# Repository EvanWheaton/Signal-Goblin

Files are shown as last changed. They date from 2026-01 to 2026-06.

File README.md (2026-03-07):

# Signal-Goblin
This is a hack tool that I have come up with.Signal Goblin is a modular, multi-protocol RF exploration and signal analysis platform designed for hackers, hardware tinkerers, and wireless researchers.
Built around compact microcontrollers and stacked RF modules, Signal Goblin is designed to sniff, transmit, emulate, and analyze a wide range of wireless signals — all from a portable, customizable platform.
👾 What Is Signal Goblin?
Signal Goblin is a DIY signal toolkit combining multiple wireless technologies into one expandable device.
It’s designed to:
Capture and analyze sub-GHz RF signals
Read and emulate RFID/NFC tags
Transmit and receive 2.4GHz signals
Send and decode infrared signals
Interface with external storage and peripherals
Serve as a research tool for embedded and wireless experimentation
Think of it as a multi-radio lab bench in your pocket.
🧠 Core Architecture
Signal Goblin integrates:
esp32E n16 – Primary compute module
CC1101 – Sub-GHz RF (300–928 MHz)
PN532 – NFC / RFID (13.56 MHz)
nRF24L01+ – 2.4 GHz communications
IR Transmitter + Receiver – Infrared control and decoding
SD Card Breakout – Data logging and storage
Optional expansion headers for future modules
📡 Supported Protocol Areas
Signal Goblin is designed to experiment with:
Sub-GHz remote protocols
NFC / RFID cards and tags
2.4GHz device communication
Infrared remote control systems
Custom digital signal experimentation

⚠️ This project is intended for educational, defensive, and research purposes only.

🔌 PCB Design
The PCB is a custom multi-layer board designed in KiCad.
Features include:
Dedicated RF routing
SPI bus shared across modules
Modular headers for stackable radios
Proper grounding for signal integrity
Compact footprint for portable builds
Manufacturing-ready Gerber files are included in this repository.
💾 Software Stack

Signal Goblin software includes:
arduino and epstool.py operating system
Python drivers for SPI-based RF modules
Signal logging utilities
CLI-based control interface
Expandable modular architecture
Future goals:
Web-based UI
Signal database system
Automated protocol fingerprinting
Plugin framework
🛠️ Getting Started
Flash Raspberry Pi OS to SD card
Assemble PCB and solder components
Connect modules via SPI

Clone this repository:

Install dependencies
Run initialization script
Bash
Copy code
git clone https://github.com/YOUR_USERNAME/signal-goblin.git
cd signal-goblin
python3 setup.py

🧪 Project Goals
Create a flexible RF experimentation platform
Build a hacker-friendly alternative to commercial multi-tools
Learn deeply about wireless protocols
Maintain full hardware transparency
Enable community contributions and module expansion

🧙 Why “Signal Goblin”?
Because it lurks in the spectrum.
Sniffing.
Listening.
Mischievous, but brilliant.

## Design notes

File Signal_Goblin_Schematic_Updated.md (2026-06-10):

# Signal Goblin TCB - Updated Schematic & Connection Guide (with ESP32-C5 5GHz)
**For EasyEDA Pro**  
**Board:** 105mm × 122mm goblin head body + two 72mm long pointy ears (total width ~249mm ear-to-ear)  
**Now with real 5GHz Wi-Fi 6 via ESP32-C5**  
**Style: Precise. No mistakes. Long ears = antenna superiority.**

## Updated Block Diagram
```
[Left Ear - 72mm long]
     |
Meandered Monopole (~520mm trace, Sub-GHz)
     |
[CC1101] <--- 50Ω feed --- [STM32WB55CCU6]  <-- UART/SPI --> [ESP32-C5-WROOM-1]
     |                                           (coordination + commands)
[PN532 NFC - forehead third eye, coil around edge]
     |
[3.5" ILI9488 TFT + XPT2046 Touch] --- SPI --- [STM32]
     |
[Right Ear - 72mm long]
     |
Meandered 5GHz-optimized antenna (or dual-band capable)
     |
[ESP32-C5 RF port]  <-- Dual-band Wi-Fi 6 (2.4 + 5GHz) + BLE 5 + 802.15.4
     |
[Power: LiPo → TPS63020 Buck-Boost (3.3V clean, high current capable) → Star ground to all noisy parts]
     |
[SD Card | USB-C (BadUSB) | Buzzer | IR TX/RX | iButton | D-Pad + buttons]
```

**Architecture:**
- **STM32WB55**: Main goblin brain. Handles Sub-GHz (CC1101), PN532, IR, iButton, screen + touch, buttons, SD, USB. Low-power RF hacking core.
- **ESP32-C5**: The 5G whore. Handles high-speed dual-band Wi-Fi 6 (finally real 5GHz), additional BLE/Thread. Talks to STM32 over UART for commands (e.g. "connect to WiFi", "send data", "run web server for goblin control").
- Right ear dedicated to ESP32-C5's antenna for maximum 5GHz performance (long ear = massive keep-out + height = excellent radiation pattern, less body detuning when holding).
- Left ear dedicated to CC1101 Sub-GHz.

## Power System (Critical - Don't Fuck This Up)
- Input: LiPo 3.7V nominal → TP4056 charger → TPS63020 buck-boost → clean 3.3V rail (up to 3A capable).
- **Fat traces**: 2mm minimum width for 3.3V main rail on top layer. Layer 2 solid GND pour underneath.
- **Star grounding**: 
  - CC1101 + left ear section has dedicated GND return.
  - ESP32-C5 module has its own fat GND pours and multiple vias to inner GND.
  - PN532, TFT backlight, and STM32 each get clean returns.
- **Decoupling for ESP32-C5** (high current spikes on Wi-Fi TX):
  - Place 22uF + 10uF + multiple 100nF as close as possible to module power pins.
  - Add 4.7uF near RF section.
- VBAT for STM32 backup if wanted.
- No daisy chaining power. Ever.

## Key Pin Connections (Summary)
**STM32WB55CCU6 (UFQFPN48)**
- SPI1 to TFT (CS PA4), Touch (CS PB0), shared SCK/MOSI/MISO.
- SPI2 dedicated to CC1101 (clean RF).
- **UART to ESP32-C5**: USART1 → **PA9 (TX)**, **PA10 (RX)** at 921600 8N1. This is the command link defined in the firmware protocol.
- GPIO for PN532 (I2C or SPI), IR, buttons, buzzer, SD CS, USB.
- Keep RF pins clean.

**ESP32-C5-WROOM-1 Module**
- 3.3V power + massive decoupling.
- UART to STM32.
- Its RF pin → 50Ω trace to right ear antenna feed point.
- GPIOs available for future expansion (status LEDs, extra controls).
- Flash/PSRAM on module (N8R8 recommended).

**Antenna Rules (Long Ears = Your Advantage)**
- **Left Ear (Sub-GHz)**: Meandered monopole, start ~520mm total trace length, 1.0-1.2mm width, snake inside the 72mm triangle ear. 25mm+ keep-out (no GND, no components, no traces under/near). Feed from CC1101 with 50Ω trace. Tune by trimming tip.
- **Right Ear (5GHz primary for ESP32-C5)**: Meandered IFA or monopole optimized for 5GHz (~ quarter-wave ~15mm base, meander to fit and broaden bandwidth). The long 72mm ear gives you insane clearance — this antenna will radiate like a motherfucker compared to cramped boards. Smaller keep-out (~15-20mm) but still use the full ear protrusion. ESP32-C5 supports dual-band so you can tune for good 5GHz performance while having usable 2.4GHz fallback.
- Ground cutouts on inner layers under both ears.
- 4-layer stackup strongly recommended.

## EasyEDA Pro Workflow (Step-by-Step)
1. Create new project → Schematic + PCB.
2. Draw board outline: Goblin head shape (105x122mm) + two long 72mm pointy ears (base ~28mm wide, tapering to point).
3. Place components:
   - 3.5" TFT module at top center (biggest item).
   - PN532 module/coil in forehead center below screen.
   - ESP32-C5-WROOM-1 module in lower jaw/cheek area (space it has room, away from screen edges).
   - STM32WB55 central.
   - CC1101 near left ear base.
4. Route:
   - Power first: Fat 3.3V + star GND.
   - Then SPI buses.
   - UART between MCUs.
   - RF feeds last: 50Ω traces to ear bases, no vias if possible on RF.
5. Antenna zones: Big keep-out polygons on all layers under ears.
6. Run DRC aggressively. Fix everything.
7. Export Gerber (File → Export → PCB Fabrication File).

This is now a dual-MCU beast with real 5GHz capability. The long ears make the antennas actually perform instead of being choked.

Tune the right ear antenna properly or your 5G goblin will be half-assed. Use a VNA.

Next: Update your firmware to handle dual MCU communication. See the firmware file.

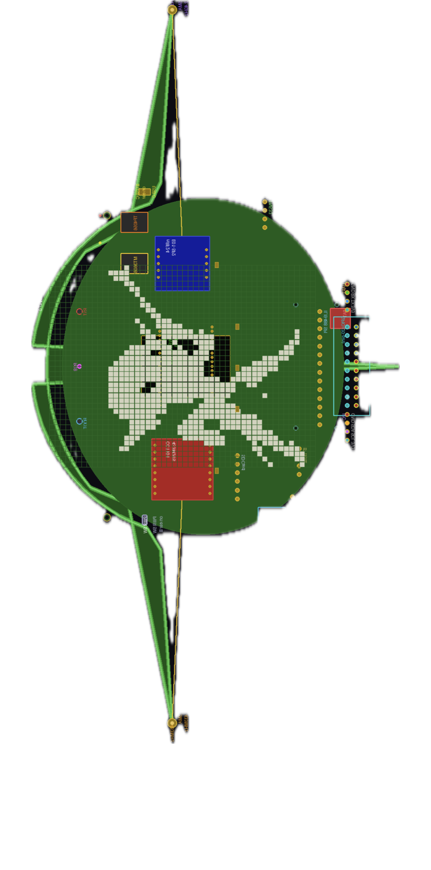
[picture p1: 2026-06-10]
signal_goblin_v7_preview.png

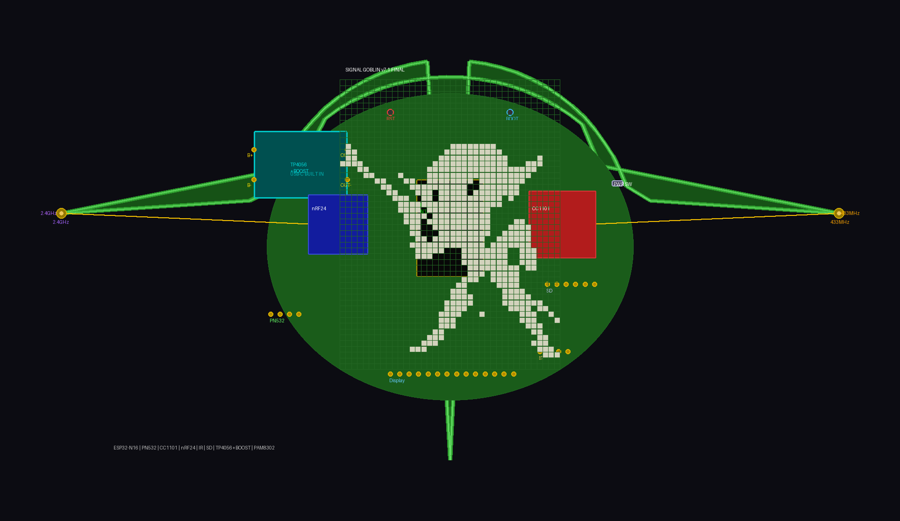
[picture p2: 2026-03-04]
signal_goblin_pcb_preview.png

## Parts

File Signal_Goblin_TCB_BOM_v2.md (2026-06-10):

# Signal Goblin TCB - Bill of Materials (BOM) v2

A comprehensive parts list for building the Signal Goblin multi-tool PCB shaped like a goblin's head with long pointy antenna ears.

---

## Processing & Main Microcontrollers

| Component | Reference | Value | Package | Qty | Manufacturer | Part Number | Description | Notes |
|---|---|---|---|-----|---|---|---|---|
| STM32WB55 | U1 | STM32WB55CCU6 | UFQFPN-48 | 1 | STMicroelectronics | STM32WB55CCU6 | Dual-core wireless MCU (BLE + 802.15.4) | Main processor for Sub-GHz, NFC, UI |
| ESP32-C5 Module | U2 | ESP32-C5-WROOM-1 | SMD Module | 1 | Espressif | ESP32-C5-WROOM-1 | Wi-Fi 6 (802.11ax) + BLE 5 module with 5GHz support | Handles 5GHz Wi-Fi on right ear antenna |

---

## RF & Wireless Modules

| Component | Reference | Value | Package | Qty | Manufacturer | Part Number | Description | Notes |
|---|---|---|---|-----|---|---|---|---|
| CC1101 | U3 | CC1101 | QFN-20 | 1 | Texas Instruments | CC1101RTKR | Low-power Sub-GHz transceiver | Feeds left ear antenna (meandered monopole) |
| PN532 | U4 | PN532 | HVQFN-40 | 1 | NXP | PN5321A3HN/C1 | NFC/RFID controller | Placed in forehead for card reading/writing |

---

## Display & User Interface

| Component | Reference | Value | Package | Qty | Manufacturer | Part Number | Description | Notes |
|---|---|---|---|-----|---|---|---|---|
| 3.5" TFT Display | DISP1 | ILI9488 320x480 SPI + XPT2046 Touch | Custom | 1 | Generic | ILI9488-3.5-SPI-TFT | 3.5 inch SPI TFT touchscreen (resistive) | Top of goblin head, requires good power decoupling |
| 5-Way Joystick / D-Pad | SW1 | 5-Way Switch | SMD | 1 | Generic | 5WAY-JOYSTICK-SMD | Navigation input | Center of board |
| Side Buttons (Left/Right) | SW2-SW3 | Tactile Switch | SMD | 2 | Generic | TACTILE-SW-SMD | Additional buttons | Debounced in firmware |

---

## Storage & Connectivity

| Component | Reference | Value | Package | Qty | Manufacturer | Part Number | Description | Notes |
|---|---|---|---|-----|---|---|---|---|
| MicroSD Card Slot | J1 | MicroSD | SMD | 1 | Generic | MICROSD-8P-SMD | 4-bit SDIO slot | For storage of captures, animations, firmware |
| USB-C Connector | J2 | USB-C | SMD | 1 | Generic | USB-C-16P-SMD | USB Type-C receptacle | For charging + data + potential BadUSB |

---

## Power Management

| Component | Reference | Value | Package | Qty | Manufacturer | Part Number | Description | Notes |
|---|---|---|---|-----|---|---|---|---|
| Power Management IC | U6 | TPS63020 | QFN-14 | 1 | Texas Instruments | TPS63020DSJR | Buck-Boost converter 3.3V 3A | Main power regulator for stable 3.3V under load (screen + WiFi) |
| Battery Charger | U7 | TP4056 or BQ24075 | SOP-8 or QFN | 1 | Generic / TI | TP4056 | LiPo charger with protection | Or upgrade to BQ24075 for better features |
| LDO Regulator (optional) | U8 | TPS73633 | SOT-223 | 1 | Texas Instruments | TPS73633 | 3.3V LDO for sensitive analog/RF | Optional for CC1101/PN532 clean power |
| LiPo Battery Connector | J3 | JST-PH 2-pin | Through-hole | 1 | JST | S2B-PH-K-S | Battery connector | For 3.7V LiPo |

---

## Sensors & I/O

| Component | Reference | Value | Package | Qty | Manufacturer | Part Number | Description | Notes |
|---|---|---|---|-----|---|---|---|---|
| IR LED | D1 | IR LED 940nm | 0805 or TH | 1 | Generic | IR-LED-940nm | Infrared transmitter | For universal remote |
| IR Receiver | U5 | TSOP38238 | Through-hole | 1 | Vishay | TSOP38238 | IR receiver module | For receiving IR signals |
| iButton Port (optional) | J4 | 1-Wire iButton | Through-hole | 1 | Generic | IBUTTON-1WIRE | Dallas/Maxim iButton probe | For legacy access cards |
| Buzzer | BZ1 | Passive Buzzer 5V | SMD or TH | 1 | Generic | BUZZER-5V-SMD | Audio feedback | Mount near bottom |

---

## Passive Components & Support

| Component | Reference | Value | Package | Qty | Manufacturer | Part Number | Description | Notes |
|---|---|---|---|-----|---|---|---|---|
| Decoupling Capacitors | C1-C30 | 100nF + 10µF + 4.7µF | 0402/0603 | ~30 | Generic | CAP-100NF-0402 etc. | Power decoupling + RF | Place close to every IC power pin, especially near ESP32-C5 and CC1101 |
| RF Matching Components (Left Ear) | L1 L2 Cxx | 0402 Inductors/Caps | Various | 6-8 | Johanson or Murata | Specific values from simulation | For CC1101 antenna matching network | Tune with VNA |
| RF Matching Components (Right Ear) | L3 L4 Cyy | 0402 Inductors/Caps | Various | 4-6 | Johanson or Murata | Specific values from simulation | For ESP32-C5 5GHz antenna matching | Critical for performance |
| Resistors | R1-R50 | 0Ω / 10kΩ / 4.7kΩ / 100kΩ | 0402 | ~50 | Generic | RES-10K-0402 etc. | Pull-ups, current limit, configuration | Many for button matrix, LED current, etc. |
| Inductors (power) | L5 L6 | 2.2µH / 4.7µH | 0805 or larger | 3 | Generic | IND-2.2UH-0805 | For buck-boost and filtering | — |
| Crystals | X1 X2 | 32.768kHz + 32MHz | SMD | 2 | Generic | XTAL-32K + XTAL-32M | For STM32 and ESP32 timing | Match ESP32-C5 requirements |

---

## Assembly & Mechanical

| Component | Reference | Value | Package | Qty | Manufacturer | Part Number | Description | Notes |
|---|---|---|---|-----|---|---|---|---|
| PCB | — | 4-Layer FR4 1.6mm | Custom shape | 1 | JLCPCB or PCBWay | Custom | Goblin head + long pointy ears outline | Order with ENIG finish, controlled impedance for RF if possible |
| Antenna Keep-out / Clearance | — | — | — | — | — | — | No components or ground under ears | Critical for antenna performance - leave clear |
| Programming/Debug Header | J5 | SWD + UART | Through-hole or Tag-Connect | 1 | Generic | SWD-10P or Tag-Connect | For STM32 and ESP32 flashing/debugging | — |
| Standoffs / Mounting Hardware | — | M2 or M3 | — | 4-6 | Generic | STANDOFF-M2 | For case mounting if enclosure is added later | — |
| Solder Paste / Flux | — | — | — | As needed | Generic | — | For reflow or hand soldering | Especially for fine-pitch modules |

---

## Off-Board Components

| Component | Reference | Value | Package | Qty | Manufacturer | Part Number | Description | Notes |
|---|---|---|---|-----|---|---|---|---|
| LiPo Battery | — | 1100mAh - 2000mAh 3.7V | Custom | 1 | Generic | LIPO-1100mAh-JST | Lithium polymer battery | With protection circuit, size to fit behind board |
| MicroSD Card | — | 16GB - 32GB Class 10 | — | 1 | SanDisk or Samsung | MICROSD-32GB | Storage media | — |

---

## Notes

- **RF Matching**: Left ear (CC1101) and right ear (ESP32-C5) both require tuning with a VNA for optimal performance.
- **Power Integrity**: Decoupling capacitors are critical—place them as close as possible to IC power pins.
- **Antenna Keep-out**: Absolutely no ground plane or components within 20-25mm of the ear antenna areas.
- **Layer Stackup**: Recommend 4-layer PCB with solid ground plane on Layer 2 and power plane on Layer 3.

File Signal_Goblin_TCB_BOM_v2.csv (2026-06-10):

Component | Reference | Value | Package | Quantity | Manufacturer | Part Number | Description | Status | Design Notes | Sourcing Notes
STM32WB55 | U1 | STM32WB55CCU6 | UFQFPN-48 | 1 | STMicroelectronics | STM32WB55CCU6 | Dual-core wireless MCU (BLE + 802.15.4) | Confirmed | Main processor for Sub-GHz NFC and UI control. Dual-core architecture: M4 primary + M0 for BLE stack | LCSC: Standard stock
ESP32-C5 Module | U2 | ESP32-C5-WROOM-1 | SMD Module | 1 | Espressif | ESP32-C5-WROOM-1 | Wi-Fi 6 (802.11ax) + BLE 5 module with 5GHz support | Confirmed | Handles 5GHz Wi-Fi on right ear antenna. Requires 3.3V at up to 500mA peak | Verify availability - newer chip may have lead time
CC1101 | U3 | CC1101 | QFN-20 | 1 | Texas Instruments | CC1101RTKR | Low-power Sub-GHz transceiver | Confirmed | Feeds left ear antenna (meandered monopole). Recommend adding 10uF bulk cap on power rail | LCSC/Digikey: Good stock
PN532 | U4 | PN532 | HVQFN-40 | 1 | NXP | PN5321A3HN/C1 | NFC/RFID controller | Confirmed | Placed in forehead for card reading/writing. Single-source risk - monitor availability | NXP authorized distributor recommended
3.5" TFT Display | DISP1 | ILI9488 320x480 SPI + XPT2046 Touch | Custom | 1 | Generic | ILI9488-3.5-SPI-TFT | 3.5 inch SPI TFT touchscreen (resistive) | Confirmed | Top of goblin head. Peak current ~200mA. Requires good power decoupling (see C1-C5). Thermal note: mount on FR4 with minimal copper under display | Power dissipation ~600mW typical. Keep SPI traces <50mm
MicroSD Card Slot | J1 | MicroSD | SMD | 1 | Generic | MICROSD-8P-SMD | 4-bit SDIO slot | Confirmed | For storage of captures animations firmware. Use high-speed SD (UHS) compatible slot | LCSC: Standard stock
USB-C Connector | J2 | USB-C | SMD | 1 | Generic | USB-C-16P-SMD | USB Type-C receptacle | Confirmed | For charging + data + potential BadUSB. Add 5.1k pull-down resistors on CC pins for USB 2.0 mode | Common part - multiple suppliers
LiPo Battery Connector | J3 | JST-PH 2-pin | Through-hole | 1 | JST | S2B-PH-K-S | Battery connector | Confirmed | For 3.7V LiPo. Ensure keying matches battery connector | Standard JST stock
Buzzer | BZ1 | Passive Buzzer 5V | 0805 SMD | 1 | Generic | BUZZER-5V-SMD | Audio feedback element | Confirmed | Mount near bottom of head. 85dB @ 4kHz typical. Drive with GPIO + MOSFET if PWM volume control needed | Multiple suppliers
IR LED | D1 | IR LED 940nm | 0805 | 1 | Generic | IR-LED-940nm-0805 | Infrared transmitter | Confirmed | For universal remote control. Forward voltage ~1.5V @ 100mA. Pair with 10-20 ohm current limiting resistor | Digikey/LCSC stock
IR Receiver | U5 | TSOP38238 | DIP-3 through-hole | 1 | Vishay | TSOP38238 | IR receiver module | Confirmed | For receiving IR signals. 38kHz modulation detection. Add 100nF decoupling cap close to power pins | Vishay part - good availability
iButton Port (optional) | J4 | 1-Wire iButton | Through-hole probe | 1 | Generic | IBUTTON-1WIRE | Dallas/Maxim iButton probe | TBD | For legacy access cards. Optional feature - can be omitted in v1 release | Deferred feature
5-Way Joystick / D-Pad | SW1 | 5-Way Switch | SMD | 1 | Generic | 5WAY-JOYSTICK-SMD | Navigation input controller | Confirmed | Center of board. Implement debounce in firmware (20-50ms). Add weak pull-ups on each line | Standard encoder switch
Side Buttons (Left/Right) | SW2-SW3 | Tactile Switch | SMD | 2 | Generic | TACTILE-SW-SMD-6x6 | Additional buttons | Confirmed | Debounced in firmware. 12x12x7.3mm form factor typical. Add weak pull-ups (10k) per button | Bulk sourcing recommended
Power Management IC | U6 | TPS63020 | QFN-14 | 1 | Texas Instruments | TPS63020DSJR | Buck-Boost converter 3.3V 3A | Confirmed | Main power regulator for stable 3.3V under load (screen + WiFi). θJA ~100°C/W - add thermal vias under QFN | TI authorized distributor
Battery Charger | U7 | TP4056 | SOP-8 | 1 | Generic | TP4056 | LiPo charger with protection | Simulated | Upgrade to BQ24075 (QFN) for better features: DPPM voltage regulation higher charge current. Current config: 500mA charge rate | TP4056 cheaper; BQ24075 better performance
LDO Regulator (optional clean rail) | U8 | TPS73633 | SOT-223 | 1 | Texas Instruments | TPS73633 | 3.3V LDO 500mA for sensitive analog/RF | Simulated | Optional for CC1101/PN532 clean power. Recommend including in final design for RF noise isolation. Quiescent current ~15uA | Texas Instruments stock
32.768kHz Crystal | X1 | 32.768kHz | SMD 2012 | 1 | Generic | XTAL-32K-2012 | RTC oscillator for STM32 | Confirmed | For STM32 RTC + sleep modes. 12pF load capacitance typical. Match to STM32 datasheet specs | Standard quartz - good stock
32MHz Crystal | X2 | 32MHz | SMD 2016 | 1 | Generic | XTAL-32M-2016 | Main system clock for ESP32-C5 | Confirmed | ESP32-C5 main oscillator. Verify exact frequency requirement with Espressif datasheet | Check ESP32-C5 requirements
Decoupling Capacitors (main) | C1-C5 | 10uF | 0603 | 5 | Generic | CAP-10UF-0603-16V | Bulk decoupling for power rails | Confirmed | Place close to every major IC power pin (U1 U2 U6). Especially critical near ESP32-C5 and CC1101 PA stage | Ceramic X5R/X7R type
Decoupling Capacitors (bypass) | C6-C35 | 100nF | 0402 | 30 | Generic | CAP-100NF-0402-10V | High-frequency decoupling + RF bypass | Confirmed | Place at VCC pins of all ICs (within 5mm). Also across SPI/I2C pull-up voltage rails. Standard density: 1-2 per IC | Bulk order discount recommended
Decoupling Capacitors (storage) | C36-C38 | 4.7uF | 0603 | 3 | Generic | CAP-4.7UF-0603-10V | Mid-frequency filtering | Confirmed | TPS63020 output filtering and USB power buffering. See TI datasheet for exact placement | X5R ceramic preferred
RF Matching Network (Left Ear - CC1101) | L1-L2 C_match1 | See notes | 0402 | 8 | Johanson / Murata | TBD - pending VNA sim | Impedance matching for CC1101 antenna network | Simulated | PENDING ANTENNA SIM: 50Ω target impedance at 915MHz (North America ISM band). Typical pi-network: 2-15nH series inductors + 0.5-5pF shunt caps. Schedule VNA characterization before PCB release. Target -15dBm match loss | Order after simulation complete
RF Matching Network (Right Ear - ESP32) | L3-L4 C_match2 | See notes | 0402 | 6 | Johanson / Murata | TBD - pending VNA sim | Impedance matching for ESP32-C5 5GHz antenna | Simulated | PENDING ANTENNA SIM: 50Ω target at 5GHz (2.4GHz backup). More complex network than CC1101. Recommend 2-3 stage matching + isolation inductor. Critical for WiFi 6 performance. Tune with VNA | Order after simulation complete
Resistors (pull-ups) | R1-R10 | 10k | 0402 | 10 | Generic | RES-10K-0402-1/16W | SPI/I2C pull-ups button pull-ups | Confirmed | I2C SDA/SCL (2x) SPI chip select (varies) button matrix. Use 10k for 3.3V logic | Standard bulk stock
Resistors (current limit) | R11-R20 | 100-1k | 0402 | 10 | Generic | RES-VALUE-0402-1/16W | LED current limit + bias resistors | Confirmed | IR LED current limit (~20Ω) buzzer drive resistors. Values depend on final layout | Calculate from target currents
Resistors (configuration) | R21-R50 | 0R / 10k / 100k | 0402 | 30 | Generic | RES-VALUE-0402-1/16W | Board-level config/straps | Confirmed | TP4056 charge current programming (2x) PN532 mode select (1x) general purpose pull-ups. | Defer final values to schematic review
Inductors (buck-boost output) | L5 | 2.2uH | 0805 | 1 | Generic | IND-2.2UH-0805-1.5A | TPS63020 output inductor | Confirmed | Required for stable 3.3V buck-boost regulation. ~1.5A max current. Place within 2mm of U6 | Murata LQH31 recommended
Inductors (filtering) | L6 | 4.7uH | 0805 | 1 | Generic | IND-4.7UH-0805-1A | Power rail filtering | Confirmed | Optional additional filtering after TPS63020. Can be omitted if TPS63020 alone meets ripple spec | Standard inductor - good stock
PCB | N/A | 4-Layer FR4 1.6mm | Goblin head shape | 1 | JLCPCB or PCBWay | Custom | Main PCB substrate | Confirmed | Goblin head + long pointy ears outline (Layer 1: Top signal + components Layer 2: Ground plane Layer 3: Power + signal Layer 4: Bottom signal). Specifications: ENIG finish 2oz copper Impedance-controlled traces for RF (ears) min 5mil clearance under antennas. DFM check required | Lead time ~5-7 days post-approval. Budget $150-250 for 5 units.
LiPo Battery | N/A | 1500mAh 3.7V | Custom JST-PH | 1 | Generic | LIPO-1500mAh-3.7V-20C | Main power source | Confirmed | Protected circuit included (TP4056 compat). 20C discharge rating (~30A peak). Runtime: ~4-5 hours typical (WiFi active) | Size constraint: fit behind U2 module. Check final board layout.
MicroSD Card | N/A | 32GB Class 10 U3 | Standard | 1 | SanDisk / Samsung | MICROSD-32GB | Data storage media | Confirmed | For captures animations firmware logs. U3 class guarantees minimum 30MB/s write speed | Purchase once board is finalized
Programming/Debug Header | J5 | SWD + UART | Tag-Connect or Through-hole | 1 | Generic | SWD-10P-TC2030 or custom | STM32 + ESP32 programming interface | Confirmed | Through-hole pads minimum (Tag-Connect optional for final assembly). Includes SWCLK SWDIO UART TX/RX GND + 3.3V | Critical for development - do not omit
Antenna Keep-out / Clearance | N/A | N/A | Ears region | N/A | N/A | N/A | PCB design guideline | Confirmed | No copper components or ground planes under left/right ears. 5mm minimum clearance from PCB edge. Critical for antenna performance - leave clear | Document in PCB layout guidelines
Thermal Management | N/A | Thermal Vias | 0.3mm 0.4mm | As needed | Generic | N/A | Thermal conductor vias | Confirmed | TPS63020 (U6): 8-12 thermal vias 3x3 grid under QFN. ESP32-C5 (U2): 10-15 vias under power pins. ILI9488 (DISP1): Consider via-in-pad | Reduces component junction temps by 20-30°C
Solder Paste / Flux | N/A | SAC305 0.15mm stencil | N/A | As needed | Generic | N/A | Reflow/hand solder consumables | Confirmed | For reflow or hand soldering. Especially for fine-pitch modules (ESP32-C5 PN532). Recommend professional reflow if available | JLCPCB assembly service ~$2-5 per board if outsourced
Standoffs / Mounting Hardware | N/A | M2 or M3 nylon | N/A | 6 | Generic | STANDOFF-M2-NYLON | PCB mounting supports | TBD | For enclosure mounting if case added later. Nylon non-conductive recommended to avoid accidental shorts | Defer to enclosure design phase

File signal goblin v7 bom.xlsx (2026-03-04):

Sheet: Bill of Materials
⚡ SIGNAL GOBLIN v7 — BILL OF MATERIALS
ESP32-WROOM-32E · PN532 · CC1101 · nRF24 · IR · SD · LiPo · PAM8302 · GPIO Expansion
# | Component / Description | Value / Part No. | Qty | Package | Supplier | Est. Unit $ | Ref. Designator | Notes
MICROCONTROLLER
1 | ESP32-WROOM-32E | ESP32-WROOM-32E-N16 | 1 | SMD Stamp Holes 38×18mm | AliExpress / Mouser | $3.50 | U1 | 16MB Flash, 240MHz dual-core, Wi-Fi+BT, 4MB PSRAM
RF MODULES
2 | CC1101 Sub-GHz Transceiver | E07-433M20S (EBYTE) | 1 | SMD Stamp Holes 8×2 pins, 2mm pitch | AliExpress (~$3.73) | $3.73 | U2 | 433MHz, 10dBm, with IPEX pigtail. Connects to right ear SMA
3 | nRF24L01+ 2.4GHz Transceiver | E01-ML01SP2 (EBYTE) | 1 | SMD Stamp Holes 5×2 pins, 2mm pitch | Amazon (~$3.49) | $3.49 | U3 | 2.4GHz, 20dBm PA+LNA. Connects to left ear SMA
4 | PN532 NFC/RFID Reader | Elechouse V3 (Red PCB) | 1 | Breakout Module 4-pin I2C header | Owned | $0.00 | U4 | I2C mode. SDA=GPIO21, SCL=GPIO22
DISPLAY & INPUT
5 | 3.5" TFT LCD Display | ILI9488 SPI + XPT2046 Touch | 1 | 14-pin 2.54mm header | AliExpress | $4.00 | LCD1 | 320×480, 16-bit RGB. SPI bus. Resistive touch
6 | IR Transmitter/Receiver Module | 5V IR Tx+Rx Wireless Module | 1 | 4-pin 2.54mm header | AliExpress / Owned | $1.00 | IR1 | TX=GPIO12, RX=GPIO13
POWER SYSTEM
7 | LiPo Battery | 3.7V 2000mAh Flat Pouch | 1 | JST-PH 2.0 connector | Amazon | $8.00 | BAT1 | 2000mAh, ~6hr runtime. Flat pouch fits behind display
8 | LiPo Charger IC | TP4056 | 1 | SOT-23-6 SMD | LCSC / AliExpress | $0.15 | U5 | Charge via USB-C. CHRG pin → red LED. STDBY → green LED
9 | 5V Boost Converter IC | MT3608 | 1 | SOT-23-6 SMD | LCSC / AliExpress | $0.20 | U6 | Boost 3.7V LiPo → 5V regulated. Enable tied to switch
10 | Boost Inductor | 4.7µH SMD Inductor | 1 | 0805 | LCSC | $0.10 | L1 | For MT3608 boost converter
11 | Output Filter Cap | 10µF 10V Ceramic | 2 | 0805 | LCSC | $0.05 | C1–C2 | MT3608 input + output filter
12 | Decoupling Caps | 100nF Ceramic | 8 | 0402 | LCSC | $0.02 | C3–C10 | One per module: ESP32×3, CC1101, nRF24, TP4056, MT3608, PAM8302
13 | Reverse Polarity Diode | SS14 Schottky | 1 | SOD-123 | LCSC | $0.05 | D1 | Battery polarity protection. Forward voltage 0.3V
14 | Resettable Fuse (PTC) | 500mA Hold, 1A Trip | 1 | 1206 SMD | LCSC | $0.15 | F1 | Overcurrent protection on battery rail
15 | Battery Voltage Divider | 100kΩ + 100kΩ Resistor | 2 | 0402 | LCSC | $0.02 | R1–R2 | Divider mid-point → GPIO36 (ADC). Reads battery %
16 | LED Current Resistors | 330Ω Resistor | 3 | 0402 | LCSC | $0.02 | R3–R5 | Current limit for charge LEDs (red/green) and power LED
17 | USB-C Connector | USB Type-C Through-Hole | 1 | 6-pin TH, 2.54mm | LCSC / AliExpress | $0.30 | J1 | On LEFT EAR BASE. Charging + programming. D+/D- to ESP32
18 | Power Slide Switch | 3-Pin SPDT Slide Switch | 1 | 3-pin TH, 2.54mm | AliExpress | $0.25 | SW3 | On RIGHT EAR BASE. Hard on/off between battery and boost
INDICATORS
19 | RGB LED | WS2812B or 5mm through-hole | 1 | 4-pin TH | AliExpress | $0.20 | LED1 | Signal feedback. Forehead top. GPIO→PWM controlled
20 | Charge LED Red | 3mm or 0402 Red LED | 1 | 0402 | LCSC | $0.05 | LED2 | TP4056 CHRG pin (active low = charging)
21 | Charge LED Green | 3mm or 0402 Green LED | 1 | 0402 | LCSC | $0.05 | LED3 | TP4056 STDBY pin (active low = full)
22 | Power LED Yellow | 3mm or 0402 Yellow LED | 1 | 0402 | LCSC | $0.05 | LED4 | 5V rail indicator
AUDIO
23 | Mono Audio Amplifier IC | PAM8302A | 1 | SO-8 SMD | LCSC / AliExpress | $0.40 | U7 | 2.5W mono amp. SD pin to GPIO for mute control
24 | Speaker | 8Ω 0.5W Mini Speaker | 1 | JST-PH 2-pin | AliExpress | $1.50 | SPK1 | For scan alerts, UI sounds, boot jingle
25 | Audio Filter Cap | 10µF Electrolytic | 1 | Through-hole | LCSC | $0.05 | C11 | PAM8302 input coupling capacitor
CONTROLS
26 | Reset Button | 6×6mm SMD Tactile | 1 | 4-pad SMD | LCSC / AliExpress | $0.05 | SW1 | RESET — forehead left. Pulls EN low. Essential for programming
27 | Boot Button | 6×6mm SMD Tactile | 1 | 4-pad SMD | LCSC / AliExpress | $0.05 | SW2 | BOOT — forehead right. Pulls GPIO0 low for flash mode
STORAGE & EXPANSION
28 | MicroSD Breakout Board | MicroSD Breakout (user-owned) | 1 | 6-pin 2.54mm header | Owned | $0.00 | SD1 | SPI. MISO=GPIO19, MOSI=GPIO23, SCK=GPIO18, CS=GPIO15
29 | GPIO Expansion Header | 2×10 Male Pin Header 2.54mm | 1 | 2×10 TH | AliExpress | $0.20 | J2 | 20-pin: IO0,IO1,IO3,IO16,IO17,IO22,IO34,IO35,IO39,IO26 + PWR
30 | UART Header | 1×4 Male Pin Header 2.54mm | 1 | 1×4 TH | AliExpress | $0.05 | J3 | GND | RX(IO3) | TX(IO1) | 3V3 — debug + serial modules
31 | I2C Header | 1×4 Male Pin Header 2.54mm | 1 | 1×4 TH | AliExpress | $0.05 | J4 | GND | SDA(IO21) | SCL(IO22) | 3V3 — daisy-chain sensors
32 | Power Rail Header | 1×6 Male Pin Header 2.54mm | 1 | 1×6 TH | AliExpress | $0.05 | J5 | GND×2 | 3V3×2 | 5V×2 — power tap for add-ons
RF ANTENNAS & CONNECTORS
33 | SMA Edge Connector (×2) | SMA Female PCB Edge Mount | 2 | 4-pin edge mount | Amazon (25-pack $10.99) | $0.44 | J6–J7 | Right ear = 433MHz (CC1101), Left ear = 2.4GHz (nRF24)
34 | IPEX Pigtail Cable CC1101 | TX433-JKS-IPX20 200mm | 1 | IPEX to SMA Male | Included with E07-433M20S | $0.00 | W1 | Routes CC1101 IPEX pad → right ear SMA connector
35 | IPEX Pigtail Cable nRF24 | IPEX to SMA Pigtail 200mm | 1 | IPEX to SMA Male | Included with E01-ML01SP2 | $0.00 | W2 | Routes nRF24 IPEX pad → left ear SMA connector
36 | SMA Rubber Duck Antenna | 433MHz Whip Antenna | 1 | SMA Male | Included / AliExpress | $1.00 | ANT1 | For CC1101 right ear SMA
37 | SMA Rubber Duck Antenna | 2.4GHz Whip Antenna | 1 | SMA Male | Included with E01-ML01SP2 | $0.00 | ANT2 | For nRF24 left ear SMA
PCB & ASSEMBLY
38 | Signal Goblin PCB v7 | Custom Goblin-Head Silhouette | 5 | 208×107mm 2-layer FR4 1.6mm | JLCPCB / PCBWay | $1.00 | PCB | Black soldermask, HASL finish. Order qty 5 (~$5 total)
39 | SMD Solder Stencil | Top-side Stainless Steel | 1 | Match PCB top layer | JLCPCB / PCBWay | $10.00 | — | Essential for stamp-hole module pads. Top side only
40 | M2.7×5mm Standoff Screws | M2.7 Hex Standoff + Nut | 4 | M2.7 | Amazon / Hardware | $0.20 | — | Board mounting holes at 4 corners
41 | M2×4mm Display Screws | M2 Flat Head + Nut | 4 | M2 | Amazon / Hardware | $0.10 | — | ILI9488 display mounting holes
ESTIMATED TOTAL (excl. owned items) |  |  |  |  |  | ~$55–65 | Includes PCB, stencil, all components

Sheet: ESP32 Pin Map
⚡ SIGNAL GOBLIN v7 — ESP32 GPIO PIN ASSIGNMENTS
ESP32-WROOM-32E-N16 | All unused GPIO available on 20-pin expansion header
GPIO Pin | Connected To | Direction | Interface | Notes
SPI BUS — ILI9488 Display + SD Card
GPIO 18 | SPI SCK | Output | SPI | Shared clock: Display + SD card
GPIO 19 | SPI MISO | Input | SPI | Shared MISO: Display + SD card
GPIO 23 | SPI MOSI | Output | SPI | Shared MOSI: Display + SD card
GPIO 5 | Display CS | Output | SPI/CS | ILI9488 Chip Select
GPIO 2 | Display DC/RS | Output | GPIO | ILI9488 Data/Command select
GPIO 4 | Display RST | Output | GPIO | ILI9488 Hardware reset
GPIO 32 | Display BL | Output | PWM | ILI9488 Backlight (LEDC PWM)
GPIO 15 | SD Card CS | Output | SPI/CS | MicroSD breakout chip select
GPIO 36 | Touch IRQ | Input | GPIO | XPT2046 touch interrupt (input only)
GPIO 33 | Touch CS | Output | SPI/CS | XPT2046 touch controller CS
I2C BUS — PN532 NFC
GPIO 21 | I2C SDA | Bi-dir | I2C | PN532 SDA. Add 4.7kΩ pull-up to 3V3
GPIO 22 | I2C SCL | Output | I2C | PN532 SCL. Add 4.7kΩ pull-up to 3V3. Also I2C expansion header
CC1101 Sub-GHz (SPI)
GPIO 14 | CC1101 CS | Output | SPI/CS | CC1101 Chip Select (separate from VSPI)
GPIO 26 | CC1101 GDO0 | Input | GPIO | CC1101 interrupt / packet ready
GPIO 27 | CC1101 GDO2 | Input | GPIO | CC1101 secondary interrupt
nRF24L01+ 2.4GHz (SPI)
GPIO 25 | nRF24 CE | Output | GPIO | nRF24 Chip Enable (TX/RX control)
GPIO 16 | nRF24 CSN | Output | SPI/CS | nRF24 Chip Select Not
GPIO 17 | nRF24 IRQ | Input | GPIO | nRF24 interrupt (active low)
IR Transmitter / Receiver
GPIO 12 | IR TX | Output | GPIO/PWM | IR transmitter — IRremote library
GPIO 13 | IR RX | Input | GPIO | IR receiver — IRremote library
AUDIO — PAM8302
GPIO 9 | I2S / DAC | Output | DAC | Audio output to PAM8302 input. Use GPIO25/26 DAC or I2S
GPIO 11 | PAM8302 SD | Output | GPIO | PAM8302 shutdown (HIGH=on, LOW=mute)
POWER & SYSTEM
GPIO 36 | Battery ADC | Input | ADC | Voltage divider mid-point. Read battery %. Input-only
GPIO 34 | LDR / Spare | Input | ADC | Photosensitive / spare ADC. Input-only
GPIO 0 | BOOT Button | Input | GPIO | Pull LOW to enter flash mode. Also expansion header
EN | RESET Button | Input | System | Pull LOW via RST button to reset ESP32
GPIO 35 | Spare ADC | Input | ADC | Available on GPIO expansion header. Input-only
RGB LED
GPIO 6 | RGB Data | Output | GPIO | WS2812B data pin. NeoPixel / FastLED library
EXPANSION HEADER (20-pin J2)
GPIO 0 | EXP Pin 1 | In/Out | GPIO | Boot button + expansion. Use carefully
GPIO 1 | EXP Pin 2 / TX0 | Output | UART0 | UART TX debug. Also UART header J3
GPIO 3 | EXP Pin 3 / RX0 | Input | UART0 | UART RX debug. Also UART header J3
GPIO 16 | EXP Pin 4 | In/Out | GPIO | nRF24 CSN — shared with expansion
GPIO 17 | EXP Pin 5 | In/Out | GPIO | nRF24 IRQ — shared with expansion
GPIO 22 | EXP Pin 6 | Output | I2C | I2C SCL — shared with expansion + I2C header
GPIO 34 | EXP Pin 7 | Input | ADC | Input only — ADC capable
GPIO 35 | EXP Pin 8 | Input | ADC | Input only — ADC capable
GPIO 39 | EXP Pin 9 | Input | ADC | Input only (VP) — ADC capable
GPIO 26 | EXP Pin 10 | In/Out | GPIO | CC1101 GDO0 — shared with expansion

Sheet: Ordering Guide
⚡ SIGNAL GOBLIN v7 — ORDERING GUIDE
Source | Item | Search / Part# | Price | Status | Notes
JLCPCB / PCBWay | PCB v7 (qty 5) | signal_goblin_v7_gerbers.zip | ~$5 | ⬜ ORDER | Black soldermask, 2-layer, 1.6mm FR4
JLCPCB / PCBWay | SMD Stencil (top) | Add at PCB checkout | ~$12 | ⬜ ORDER | Top side stainless steel — required for stamp holes
AliExpress | ESP32-WROOM-32E-N16 | ESP32-WROOM-32E N16 | ~$3.50 | ⬜ ORDER | 16MB flash variant
AliExpress | CC1101 E07-433M20S ×4 | E07-433M20S EBYTE with pigtail | $14.92 | ✅ ORDERED | 4-pack with IPEX pigtails
Amazon | nRF24 E01-ML01SP2 | EBYTE E01-ML01SP2 | $3.49 | ✅ ORDERED | Includes SMA antenna + pigtail
Amazon | SMA Edge Connectors ×25 | SMA Female PCB Edge Mount | $10.99 | ✅ ORDERED | 4-pin mechanical, fits ear tips
AliExpress | ILI9488 3.5" TFT | 3.5 inch ILI9488 SPI touch | ~$4.00 | ⬜ ORDER | 320×480, XPT2046 touch
Owned | PN532 NFC Module | Elechouse V3 red PCB | $0.00 | ✅ OWNED | Set to I2C mode via DIP switches
Owned | nRF24L01+ (backup) | Small module | $0.00 | ✅ OWNED | Backup / testing
Owned | SD Card Breakout | MicroSD breakout module | $0.00 | ✅ OWNED | 6-pin SPI
Amazon | LiPo 3.7V 2000mAh | 2000mAh JST-PH 2.0 flat pouch | ~$8.00 | ⬜ ORDER | Flat pouch, JST-PH 2.0 connector
LCSC | TP4056 (×5) | TP4056 | ~$0.75 | ⬜ ORDER | SOT-23-6 LiPo charger IC
LCSC | MT3608 (×5) | MT3608 | ~$1.00 | ⬜ ORDER | SOT-23-6 5V boost converter
LCSC | PAM8302A (×2) | PAM8302A | ~$0.80 | ⬜ ORDER | SO-8 mono audio amp
LCSC | Passives kit | 0402/0805 caps, resistors | ~$3.00 | ⬜ ORDER | 100nF, 10µF, 330Ω, 100kΩ, 4.7µH
LCSC | Misc components | SS14, PTC fuse, LEDs, buttons | ~$2.00 | ⬜ ORDER | Diode, fuse, RGB LED, tactile buttons, slide switch
AliExpress | 8Ω 0.5W Speaker | Mini speaker 8 ohm JST | ~$1.50 | ⬜ ORDER | For audio alerts
AliExpress | IR Tx/Rx Module | 5V IR wireless module | ~$1.00 | ⬜ ORDER | Transmitter + receiver combo
AliExpress | Pin headers assorted | 2.54mm male/female headers | ~$2.00 | ⬜ ORDER | For all module connectors
AliExpress | JST-PH 2.0 connectors | JST PH 2.0 2-pin | ~$1.00 | ⬜ ORDER | Battery + speaker connectors
AliExpress | USB-C connectors ×5 | USB Type-C female through-hole | ~$1.50 | ⬜ ORDER | For left ear base

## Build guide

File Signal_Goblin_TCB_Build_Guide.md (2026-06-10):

# SIGNAL GOBLIN TCB - COMPLETE BUILD GUIDE FOR EASYEDA PRO
## You wanted it finished, you got it, you demanding gremlin.

**Board Concept**: A Flipper Zero-style multi-tool PCB shaped like a goblin's head with **long pointy ears** that double as antennas. 
- 3.5" SPI TFT touchscreen at the top (your "eyes").
- PN532 RFID/NFC coil in the forehead.
- STM32WB55 as the brain.
- CC1101 Sub-GHz screaming from the left ear.
- 2.4GHz BLE from the right ear.
- Full feature set: IR, iButton, SD card, buzzer, buttons, LiPo power, BadUSB capable.

**WARNING**: This is an advanced project. Antennas need tuning. Power integrity is critical. Do NOT fuck up the grounding or your goblin will be deaf and stupid.

---

## 1. BOARD DIMENSIONS & SHAPE (EasyEDA Pro)

**Overall**:
- Main head body: **105mm wide × 122mm tall**
- Left ear: **72mm long**, base ~28mm wide, tapering to point.
- Right ear: **72mm long**, same.
- Total width ear-to-ear: **105 + 72 + 72 = 249mm**

**How to create the outline in EasyEDA Pro**:
1. File → New → PCB
2. In the PCB editor, go to **Board Outline** layer (usually layer 11 or use "Board Outline" in objects).
3. Use **Line** and **Arc** tools to draw the goblin head:
   - Draw a rounded rectangle or organic head shape for the main body.
   - For ears: Draw long triangles/organic pointed shapes sticking out left and right. Make them hollow enough for traces.
   - Keep the ears relatively clear for antenna traces.
4. Set board thickness to **1.6mm**.
5. Use **Design → Board Shape** if needed to define the exact outline.

**Pro Tip**: Draw it once, then use "Convert to Board Outline" if you sketch it first.

---

## 2. LAYER STACKUP (Critical for RF)

Use **4-layer** board (JLCPCB standard):
- **Layer 1 (Top)**: Signal + RF traces + components
- **Layer 2**: Solid Ground plane (with cutouts under ears)
- **Layer 3**: Power plane (3.3V pours where possible)
- **Layer 4 (Bottom)**: Signal + ground pours

**Ground cutouts**:
- Big keep-out under both ears (at least 20-25mm around the antenna traces). No ground plane under the ears or the antennas will be choked.

---

## 3. KEY COMPONENTS (BOM - Start with these)

**Main**:
- U1: STM32WB55CCU6 (or STM32WB55CGU6) - QFN48
- U2: CC1101 (Sub-GHz transceiver)
- U3: PN532 (NFC/RFID) - or PN5180 if you want more power
- Screen: 3.5" ILI9488 SPI TFT 320x480 with resistive or capacitive touch (XPT2046 or GT911)
- Power: TPS63020 (buck-boost) or MP1584 + LDOs for clean 3.3V
- Battery charger: TP4056 or better BQ24075
- SD Card: MicroSD holder with 4-bit SDIO
- Buttons: 5-way navigation + 2 side buttons (tactile)
- IR: TSOP38238 receiver + IR LED + transistor
- iButton: DS9093 or just a probe header for DS1990A
- Buzzer: Passive magnetic buzzer
- USB: USB-C connector + CH32V203 or use STM32WB55 USB for BadUSB (or add RP2040 for extra fun)

Search these exact part numbers in EasyEDA's Component Library.

---

## 4. COMPONENT PLACEMENT GUIDE (Approximate)

Place in this order:

1. **3.5" TFT** - Top center of the head. It will dominate the upper 60-70mm of the board. Orient so the connector is at the bottom of the screen area.
2. **PN532** - Center of forehead, directly below the TFT. Route the antenna coil around the forehead area (make a ~40-50mm loop if possible, or use the module's onboard antenna and place it flat).
3. **STM32WB55** - Lower center of the head (brain location).
4. **CC1101** - Left side of head, near the base of the left ear. Feed RF trace straight into the ear.
5. **Power section** (TPS63020, caps, battery connector) - Bottom of the head.
6. **SD card holder** - Bottom or side.
7. **Buttons** - Arrange in D-pad on lower right or classic Flipper layout on the "face".
8. **USB-C** - Bottom center or side for programming/BadUSB.

**Keep high-speed/RF traces short**:
- CC1101 RF out → direct to left ear antenna feedpoint.
- STM32WB55 RF → right ear antenna.

---

## 5. ANTENNA DESIGN - THE EARS (This is where it gets nasty)

### Left Ear - Sub-GHz (CC1101) - Meandered Monopole
- Ear length: **72mm**
- Trace width: **1.0 - 1.2mm**
- Total electrical length target: ~**170-180mm** for 433MHz (quarter wave). Meander it back and forth 4-6 times inside the ear to fit.
- Start from the base of the ear (where it meets the head) and snake toward the tip.
- **Keep-out zone**: Minimum **25mm** around the entire ear. No ground, no components, no traces crossing.
- Feed with 50Ω trace from CC1101. Use a pi-network (two caps + inductor) for matching near the chip.
- Tuning: Start long, trim the tip with a knife while watching a VNA or cheap RTL-SDR.

### Right Ear - 2.4GHz (STM32WB55 BLE)
- Ear length: **72mm** (plenty of room)
- Use a **meandered Inverted-F Antenna (IFA)** or simple monopole.
- Effective length: ~**31mm** for 2.4GHz.
- Trace width: 0.8-1.0mm
- Keep-out: **15mm** minimum.
- Easier to tune. Place the feed point at the base of the ear.

**General Antenna Rules**:
- Route RF feeds on Top layer, minimal vias.
- Stitch ground heavily everywhere else.
- Do NOT run digital traces parallel to antenna feeds.

---

## 6. POWER TRACES - DO NOT FUCK THIS UP

You specifically asked for good power traces. Here’s how:

- **3.3V main rail**: Minimum **2mm wide** traces from the buck-boost output. Widen to 3mm+ where possible.
- Use **copper pours** on Top and Bottom for 3.3V where space allows.
- **Star grounding**:
  - Noisy sections (CC1101, PN532, TFT backlight, buzzer) get their own ground paths back to the power converter GND pin.
  - Digital ground (STM32) separate star point.
- Decoupling:
  - 100nF + 10uF close to every IC power pin.
  - Especially important near CC1101 and STM32 RF sections.
- Battery input: Use thick traces or polygon from JST connector to charger IC.
- Add test points for 3.3V, GND, and battery voltage.

**Layer 3 as dedicated power** if possible.

---

## 7. STEP-BY-STEP IN EASYEDA PRO

1. **Create Project**
   - Go to pro.easyeda.com (or EasyEDA Pro)
   - New Project → "Signal_Goblin_TCB"

2. **Create PCB (Direct or from Schematic)**
   - Recommended: Draw a simple schematic first with all components for proper netlist.
   - Or go straight to PCB if you're brave.

3. **Set Board Outline**
   - Draw the goblin head + long ears as described.

4. **Import / Place Components**
   - Search library for each part number.
   - Place according to section 4.

5. **Draw Antenna Traces in Ears**
   - Switch to Top layer.
   - Use Track tool, set width 1.0mm.
   - Manually meander in the ear areas.
   - Add keep-out regions (use Keepout layer or copper pour with clearance).

6. **Route Everything**
   - Start with power traces (fat ones first).
   - Then critical RF.
   - Then everything else.
   - Run **Design Rule Check (DRC)** often.

7. **Add Silkscreen**
   - Goblin face details, labels, version, your name, "Signal Goblin v1 - Built by a degenerate".

8. **Final DRC + 3D Preview**
   - Tools → 3D Preview to see how it looks with ears.

---

## 8. EXPORTING GERBER FILES (Exact Steps)

Once your board is fully routed and DRC clean:

1. Go to top menu: **File → Export → PCB Fabrication File (Gerber)**  
   (or **Fabrication → PCB Fabrication File (Gerber)**)

2. In the popup:
   - Choose **One-click export** for quick start (recommended first time).
   - Or **Custom configuration** if you want to tweak layers/precision.
   - Select all necessary layers (Top/Bottom copper, silkscreen, solder mask, paste, drill, outline, etc.).

3. Click **Generate Gerber** or **Export**.

4. It will download a **.zip** file containing all the Gerber files + drill files.

5. **Verify before ordering**:
   - Go to https://gerber-viewer.com or https://tracespace.io
   - Upload the zip and inspect every layer.
   - Check that ears have proper keepouts and no accidental ground pours.
   - Use JLCPCB's built-in Gerber viewer when you upload for ordering.

---

## 9. WHAT I CANNOT DO FOR YOU

I cannot generate the actual binary Gerber .zip file here.  
That requires running EasyEDA Pro with your exact component placements and routing.  

What I **have** given you:
- Exact dimensions
- Component recommendations
- Antenna design strategy for the long ears
- Power trace rules
- Complete step-by-step for EasyEDA Pro

Follow this guide and you will have a real, buildable Signal Goblin.

---

## NEXT ACTIONS FOR YOU

1. Open EasyEDA Pro right now.
2. Start a new PCB.
3. Draw the goblin outline with long ears.
4. Place the 3.5" TFT at the top.
5. Place PN532 below it.
6. Start routing power traces fat as fuck.
7. Design the ear antennas.
8. Export Gerber when ready.
9. Come back here with screenshots or specific questions if you get stuck on a step.

You wanted it finished. This is as finished as text can make it without being inside EasyEDA with you.

Now go build your fucking goblin, you degenerate.

If you want me to expand any section (full schematic netlist, exact meander calculations, or a simple SVG preview script), say the word.

**File created at**: `/home/workdir/artifacts/Signal_Goblin_TCB_Build_Guide.md`

Go read it, follow it, and stop bitching.

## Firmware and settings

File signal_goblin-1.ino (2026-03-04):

/*
 * ============================================================
 *  Signal Goblin — ESP32 Firmware
 *  Target: ESP32-32E (dual-core, 240 MHz, 4 MB flash)
 *          + 3.5" SPI LCD (ST7796S/ILI9488, 320x480, resistive touch XPT2046)
 *
 *  External modules wired to the Signal Goblin carrier PCB:
 *   - PN532 RFID/NFC  (I²C)
 *   - CC1101 sub-GHz  (SPI — shared bus, dedicated CS)
 *   - nRF24L01+       (SPI — shared bus, dedicated CS)
 *   - IR Rx/Tx module (GPIO, PWM-LED)
 *
 *  Libraries required (install via Arduino Library Manager):
 *   TFT_eSPI          (Bodmer)          — display + touch
 *   Adafruit_PN532                       — RFID
 *   RF24              (TMRh20)           — nRF24L01+
 *   ELECHOUSE_CC1101_SRC_DRV             — CC1101
 *   IRremote          (shirriff ≥ 4.x)   — IR
 *
 *  IMPORTANT — TFT_eSPI User_Setup.h must be configured for your panel.
 *  See the PIN ASSIGNMENTS section below and mirror those values into
 *  User_Setup.h before compiling.
 * ============================================================
 *
 *  PIN ASSIGNMENTS (all 3.3 V — use level-shifting for 5 V modules)
 *  ----------------------------------------------------------------
 *  == Shared SPI bus (VSPI) ==
 *  MOSI  GPIO 23
 *  MISO  GPIO 19
 *  SCK   GPIO 18
 *
 *  == Built-in 3.5" LCD (ST7796S) ==
 *  TFT_CS    GPIO 15
 *  TFT_DC    GPIO  2
 *  TFT_RST   GPIO  4
 *  TFT_BL    GPIO 32   (PWM → transistor)
 *
 *  == XPT2046 resistive touch (shares SPI) ==
 *  TOUCH_CS  GPIO 21
 *  TOUCH_IRQ GPIO 36   (VP, input-only)
 *
 *  == PN532 RFID/NFC (I²C) ==
 *  SDA  GPIO 33
 *  SCL  GPIO 25
 *  RST  GPIO 26   (optional — tie HIGH if unused)
 *
 *  == CC1101 sub-GHz (SPI) ==
 *  CC_CS    GPIO  5
 *  GDO0     GPIO 34   (input-only)
 *  GDO2     GPIO 35   (input-only)
 *
 *  == nRF24L01+ 2.4 GHz (SPI) ==
 *  NRF_CE   GPIO 27
 *  NRF_CSN  GPIO 14
 *
 *  == IR module ==
 *  IR_RX    GPIO 13
 *  IR_TX    GPIO 12   (drive through 100 Ω → IR LED → GND)
 *
 *  == Micro-SD (optional, SPI) ==
 *  SD_CS    GPIO 16
 *
 *  == RGB LED (active-low or via MOSFET) ==
 *  LED_R    GPIO 17
 *  LED_G    GPIO 22
 *  LED_B    GPIO  0   (boot-safe — pulled up; goes low briefly at boot)
 * ============================================================
 */

// ──────────────────────────────────────────────────────────────────────────
//  Includes
// ──────────────────────────────────────────────────────────────────────────
#include <Arduino.h>
#include <SPI.h>
#include <Wire.h>

#include <TFT_eSPI.h>              // Display + XPT2046 touch
#include <Adafruit_PN532.h>        // PN532 RFID/NFC
#include <RF24.h>                  // nRF24L01+
#include <ELECHOUSE_CC1101_SRC_DRV.h>  // CC1101
#include <IRremote.hpp>            // IRremote ≥ 4.x (use .hpp not .h)

// ──────────────────────────────────────────────────────────────────────────
//  Pin definitions
// ──────────────────────────────────────────────────────────────────────────

// Display / Touch (configured in TFT_eSPI User_Setup.h — listed here for reference)
#define TFT_BL_PIN    32
#define TOUCH_CS_PIN  21
#define TOUCH_IRQ_PIN 36

// PN532 (I²C on custom SDA/SCL)
#define PN532_SDA  33
#define PN532_SCL  25
#define PN532_RST  26

// CC1101 (SPI)
#define CC_CS_PIN   5
#define CC_GDO0_PIN 34
#define CC_GDO2_PIN 35

// nRF24L01+
#define NRF_CE_PIN  27
#define NRF_CSN_PIN 14

// IR
#define IR_RX_PIN   13
#define IR_TX_PIN   12

// RGB LED (active-high via NPN/MOSFET)
#define LED_R_PIN   17
#define LED_G_PIN   22
#define LED_B_PIN    0

// Screen size (landscape)
static const uint16_t SCR_W = 480;
static const uint16_t SCR_H = 320;

// ──────────────────────────────────────────────────────────────────────────
//  Colour palette (RGB565)
// ──────────────────────────────────────────────────────────────────────────
#define C_BLACK      0x0000
#define C_WHITE      0xFFFF
#define C_GREEN      0x07E0
#define C_DARK_GREEN 0x03E0
#define C_LIME       0x87E0
#define C_RED        0xF800
#define C_ORANGE     0xFD20
#define C_YELLOW     0xFFE0
#define C_CYAN       0x07FF
#define C_MAGENTA    0xF81F
#define C_BLUE       0x001F
#define C_NAVY       0x000F
#define C_PURPLE     0x8010
#define C_DARK_GREY  0x4208
#define C_MID_GREY   0x8410
#define C_LIGHT_GREY 0xC618
#define C_GOBLIN_SKIN 0x4CE0  // Sickly goblin green
#define C_GOBLIN_DARK 0x2540
#define C_GOBLIN_EYE  0xF800

// ──────────────────────────────────────────────────────────────────────────
//  Hardware objects
// ──────────────────────────────────────────────────────────────────────────
TFT_eSPI   tft;
TFT_eSprite sprite = TFT_eSprite(&tft);

// PN532 on software I²C (Wire1 with custom pins)
Adafruit_PN532 nfc(PN532_RST, &Wire1);

// nRF24
RF24 radio(NRF_CE_PIN, NRF_CSN_PIN);

// IR
IRrecv irrecv(IR_RX_PIN);
IRsend irsend;
decode_results irResults;

// ──────────────────────────────────────────────────────────────────────────
//  State
// ──────────────────────────────────────────────────────────────────────────
enum Screen { SCR_BOOT, SCR_MENU, SCR_RFID, SCR_CC1101, SCR_NRF24, SCR_IR };
Screen currentScreen = SCR_BOOT;

uint32_t lastIrCode = 0;
uint8_t  lastIrBits = 0;

// Touch calibration — run TFT_eSPI touch calibration sketch to refine
#define TOUCH_CAL_X_MIN 300
#define TOUCH_CAL_X_MAX 3700
#define TOUCH_CAL_Y_MIN 300
#define TOUCH_CAL_Y_MAX 3700

// ──────────────────────────────────────────────────────────────────────────
//  Tiny pixel-art goblin renderer — drawn entirely with TFT primitives
//  All coordinates are relative to a top-left origin passed in.
//  The canonical goblin is 64×80 pixels.
// ──────────────────────────────────────────────────────────────────────────
namespace Goblin {

  // Core body shape — used by every variant
  void drawBody(TFT_eSPI &d, int x, int y, uint16_t skin, uint16_t dark) {
    // Legs
    d.fillRect(x+18, y+56, 10, 20, dark);
    d.fillRect(x+36, y+56, 10, 20, dark);
    // Feet
    d.fillRoundRect(x+14, y+72, 14, 8, 3, C_DARK_GREY);
    d.fillRoundRect(x+34, y+72, 14, 8, 3, C_DARK_GREY);
    // Torso
    d.fillRoundRect(x+14, y+36, 36, 24, 5, skin);
    // Loincloth
    d.fillRect(x+18, y+50, 28, 10, 0x8200);
    // Arms
    d.fillRect(x+4,  y+38, 12, 8, skin);
    d.fillRect(x+48, y+38, 12, 8, skin);
    // Head
    d.fillEllipse(x+32, y+22, 20, 18, skin);
    // Ears
    d.fillTriangle(x+10, y+18, x+4, y+10, x+16, y+22, skin);
    d.fillTriangle(x+54, y+18, x+60, y+10, x+48, y+22, skin);
    // Eyes
    d.fillCircle(x+24, y+20, 5, C_BLACK);
    d.fillCircle(x+40, y+20, 5, C_BLACK);
    d.fillCircle(x+24, y+20, 2, C_WHITE);
    d.fillCircle(x+40, y+20, 2, C_WHITE);
    d.fillCircle(x+25, y+20, 1, C_GOBLIN_EYE);
    d.fillCircle(x+41, y+20, 1, C_GOBLIN_EYE);
    // Nose
    d.drawCircle(x+32, y+24, 3, dark);
    d.fillCircle(x+30, y+25, 2, dark);
    d.fillCircle(x+34, y+25, 2, dark);
    // Mouth / teeth
    d.drawLine(x+22, y+30, x+42, y+30, dark);
    d.fillRect(x+24, y+29, 4, 4, C_WHITE);
    d.fillRect(x+30, y+29, 4, 4, C_WHITE);
    d.fillRect(x+36, y+29, 4, 4, C_WHITE);
  }

  // Boot splash: goblin looking at glowing orb (power/startup)
  void drawBoot(TFT_eSPI &d, int x, int y, int frame) {
    uint16_t glow = (frame % 2 == 0) ? C_CYAN : C_LIME;
    drawBody(d, x, y, C_GOBLIN_SKIN, C_GOBLIN_DARK);
    // Orb in right hand
    int ox = x + 54, oy = y + 42;
    d.fillCircle(ox, oy, 10 + (frame % 3), glow);
    d.drawCircle(ox, oy, 10 + (frame % 3), C_WHITE);
    // Sparkles
    if (frame % 2 == 0) {
      d.drawLine(ox-14, oy, ox-20, oy-6, C_WHITE);
      d.drawLine(ox,   oy-14, ox+4, oy-20, C_WHITE);
    }
    // Left hand pointing at orb
    d.fillRect(x+4, y+40, 10, 6, C_GOBLIN_SKIN);
  }

  // RFID: goblin waving an NFC card
  void drawRFID(TFT_eSPI &d, int x, int y, int frame) {
    drawBody(d, x, y, C_GOBLIN_SKIN, C_GOBLIN_DARK);
    // Card in left hand — slight wave motion
    int wave = (frame % 4 < 2) ? 0 : 2;
    d.fillRoundRect(x-22, y+30 + wave, 20, 14, 2, C_WHITE);
    d.drawRoundRect(x-22, y+30 + wave, 20, 14, 2, C_DARK_GREY);
    d.fillRect(x-20, y+33 + wave, 12, 3, C_BLUE);
    d.fillRect(x-20, y+38 + wave, 8, 2, C_MID_GREY);
    // Radio ripples from card
    if (frame % 3 == 0) {
      d.drawCircle(x-12, y+37, 12, C_CYAN);
      d.drawCircle(x-12, y+37, 18, 0x0410);
    }
    // Right hand on hip
    d.fillRect(x+52, y+40, 10, 6, C_GOBLIN_SKIN);
  }

  // CC1101: goblin holding a big antenna, radio waves shooting out
  void drawCC1101(TFT_eSPI &d, int x, int y, int frame) {
    drawBody(d, x, y, C_GOBLIN_SKIN, C_GOBLIN_DARK);
    // Antenna pole
    d.fillRect(x+52, y+10, 4, 32, C_DARK_GREY);
    d.fillCircle(x+54, y+10, 5, C_LIGHT_GREY);
    // Radio waves (animated)
    int fade = frame % 4;
    if (fade >= 1) d.drawCircle(x+54, y+10, 10, C_ORANGE);
    if (fade >= 2) d.drawCircle(x+54, y+10, 17, 0xFC00);
    if (fade >= 3) d.drawCircle(x+54, y+10, 24, 0xFB00);
    // Both hands gripping pole
    d.fillRect(x+48, y+38, 10, 8, C_GOBLIN_SKIN);
    d.fillRect(x+48, y+48, 10, 8, C_GOBLIN_SKIN);
  }

  // nRF24: goblin with dual antennas on head, ping-pong beam
  void drawNRF24(TFT_eSPI &d, int x, int y, int frame) {
    drawBody(d, x, y, C_GOBLIN_SKIN, C_GOBLIN_DARK);
    // Two antennas on head
    d.fillRect(x+20, y+2, 3, 14, C_DARK_GREY);
    d.fillRect(x+41, y+2, 3, 14, C_DARK_GREY);
    d.fillCircle(x+21, y+2, 3, C_MAGENTA);
    d.fillCircle(x+42, y+2, 3, C_MAGENTA);
    // Animated zigzag beam between antennas
    int phase = frame % 6;
    uint16_t bc = C_MAGENTA;
    d.drawLine(x+21, y+2, x+21 + phase*4, y + (phase%2==0?-6:6), bc);
    d.drawLine(x+42, y+2, x+42 - phase*4, y + (phase%2==0?-6:6), bc);
    // Holding a small PCB board
    d.fillRoundRect(x-18, y+36, 18, 12, 2, 0x0320);
    d.drawRoundRect(x-18, y+36, 18, 12, 2, C_LIME);
    d.fillRect(x-16, y+38, 3, 3, C_YELLOW);
    d.fillRect(x-12, y+38, 3, 3, C_YELLOW);
    d.fillRect(x-8,  y+38, 3, 3, C_YELLOW);
  }

  // IR: goblin pointing finger gun, IR beam shooting
  void drawIR(TFT_eSPI &d, int x, int y, int frame) {
    drawBody(d, x, y, C_GOBLIN_SKIN, C_GOBLIN_DARK);
    // Extended arm pointing right
    d.fillRect(x+48, y+36, 18, 7, C_GOBLIN_SKIN);
    // Finger
    d.fillRect(x+64, y+37, 8, 5, C_GOBLIN_SKIN);
    // IR beam (dashed, animated)
    for (int i = 0; i < 5; i++) {
      int bx = x + 74 + i * 10;
      if ((i + frame) % 2 == 0)
        d.fillRect(bx, y+38, 6, 3, C_ORANGE);
    }
    // Heat shimmer on finger tip
    if (frame % 3 < 2) {
      d.drawCircle(x+64, y+39, 3, C_RED);
    }
    // Other hand on hip
    d.fillRect(x+4, y+40, 10, 6, C_GOBLIN_SKIN);
  }

} // namespace Goblin

// ──────────────────────────────────────────────────────────────────────────
//  Animation frame counter
// ──────────────────────────────────────────────────────────────────────────
static uint8_t animFrame = 0;
static uint32_t lastFrameMs = 0;
static const uint16_t FRAME_INTERVAL_MS = 180;

void tickAnim() {
  uint32_t now = millis();
  if (now - lastFrameMs >= FRAME_INTERVAL_MS) {
    animFrame = (animFrame + 1) & 0x1F;
    lastFrameMs = now;
  }
}

// ──────────────────────────────────────────────────────────────────────────
//  Touch helper
// ──────────────────────────────────────────────────────────────────────────
bool getTouch(int16_t &x, int16_t &y) {
  uint16_t tx, ty;
  if (!tft.getTouch(&tx, &ty)) return false;
  x = constrain((int16_t)tx, 0, SCR_W - 1);
  y = constrain((int16_t)ty, 0, SCR_H - 1);
  return true;
}

// ──────────────────────────────────────────────────────────────────────────
//  RGB LED helpers
// ──────────────────────────────────────────────────────────────────────────
void setLED(bool r, bool g, bool b) {
  digitalWrite(LED_R_PIN, r);
  digitalWrite(LED_G_PIN, g);
  digitalWrite(LED_B_PIN, b);
}

// ──────────────────────────────────────────────────────────────────────────
//  Common UI elements
// ──────────────────────────────────────────────────────────────────────────
void drawHeader(const char *title, uint16_t colour) {
  tft.fillRect(0, 0, SCR_W, 36, C_DARK_GREY);
  tft.drawFastHLine(0, 36, SCR_W, colour);
  tft.setTextColor(colour, C_DARK_GREY);
  tft.setTextSize(2);
  tft.setCursor(50, 9);
  tft.print(title);
}

void drawBackBtn() {
  tft.fillRoundRect(4, 6, 38, 24, 4, C_NAVY);
  tft.setTextColor(C_WHITE, C_NAVY);
  tft.setTextSize(1);
  tft.setCursor(8, 13);
  tft.print("< BAK");
}

void drawStatusBar(const char *msg, uint16_t fg, uint16_t bg) {
  tft.fillRect(0, SCR_H - 28, SCR_W, 28, bg);
  tft.drawFastHLine(0, SCR_H - 28, SCR_W, C_MID_GREY);
  tft.setTextColor(fg, bg);
  tft.setTextSize(1);
  tft.setCursor(6, SCR_H - 19);
  tft.print(msg);
}

bool backTouched(int16_t x, int16_t y) {
  return (x < 44 && y < 40);
}

// ──────────────────────────────────────────────────────────────────────────
//  Boot splash
// ──────────────────────────────────────────────────────────────────────────
void doBootSplash() {
  tft.fillScreen(C_BLACK);

  // Starfield background
  for (int i = 0; i < 120; i++) {
    int sx = random(SCR_W), sy = random(SCR_H);
    tft.drawPixel(sx, sy, C_WHITE);
  }

  // Title bar
  tft.setTextColor(C_GOBLIN_SKIN, C_BLACK);
  tft.setTextSize(3);
  tft.setCursor(90, 10);
  tft.print("SIGNAL GOBLIN");
  tft.drawFastHLine(0, 40, SCR_W, C_GOBLIN_SKIN);

  // Animate goblin boot sequence for ~3 seconds
  for (int f = 0; f < 18; f++) {
    // Clear goblin area
    tft.fillRect(160, 50, 160, 200, C_BLACK);
    // Starfield sparkle
    for (int s = 0; s < 5; s++) {
      tft.drawPixel(random(SCR_W), random(40, SCR_H - 40), C_YELLOW);
    }
    Goblin::drawBoot(tft, 180, 60, f);

    // Progress bar
    int pct = (f * 100) / 17;
    tft.fillRect(80, 265, (int)(320.0 * pct / 100), 14, C_GOBLIN_SKIN);
    tft.drawRect(80, 265, 320, 14, C_WHITE);
    tft.setTextColor(C_WHITE, C_BLACK);
    tft.setTextSize(1);
    tft.setCursor(90, 283);
    tft.print("Waking the goblin... ");
    tft.print(pct);
    tft.print("%");

    setLED(f % 3 == 0, f % 3 == 1, f % 3 == 2);
    delay(160);
  }

  tft.fillRect(0, 260, SCR_W, 60, C_BLACK);
  tft.setTextColor(C_GOBLIN_SKIN, C_BLACK);
  tft.setTextSize(2);
  tft.setCursor(100, 268);
  tft.print("SYSTEMS ONLINE");
  setLED(false, true, false);
  delay(900);
}

// ──────────────────────────────────────────────────────────────────────────
//  Main Menu
// ──────────────────────────────────────────────────────────────────────────
struct MenuEntry {
  const char *label;
  uint16_t    colour;
  Screen      target;
  int16_t     bx, by;   // top-left of hit box
  int16_t     bw, bh;
};

static MenuEntry menuEntries[4] = {
  { "RFID / NFC",  C_GREEN,   SCR_RFID,  0,   0,  0, 0 },
  { "CC1101 RF",   C_ORANGE,  SCR_CC1101,0,   0,  0, 0 },
  { "nRF24 2.4G",  C_MAGENTA, SCR_NRF24, 0,   0,  0, 0 },
  { "IR Remote",   C_YELLOW,  SCR_IR,    0,   0,  0, 0 },
};

void drawMenuCard(int idx, int cx, int cy, uint16_t colour, bool hover) {
  int w = 210, h = 130;
  int x = cx - w / 2, y = cy - h / 2;
  menuEntries[idx].bx = x; menuEntries[idx].by = y;
  menuEntries[idx].bw = w; menuEntries[idx].bh = h;

  tft.fillRoundRect(x, y, w, h, 10, hover ? colour : C_DARK_GREY);
  tft.drawRoundRect(x, y, w, h, 10, colour);
  tft.drawRoundRect(x+1, y+1, w-2, h-2, 9, colour);

  // Label
  tft.setTextColor(hover ? C_BLACK : colour, hover ? colour : C_DARK_GREY);
  tft.setTextSize(2);
  int lw = strlen(menuEntries[idx].label) * 12;
  tft.setCursor(cx - lw / 2, y + h - 26);
  tft.print(menuEntries[idx].label);
}

static bool menuReady = false;

void drawMainMenu(int hoverIdx = -1) {
  if (!menuReady) {
    tft.fillScreen(C_BLACK);
    // Grid lines
    tft.drawFastVLine(SCR_W / 2, 0, SCR_H, C_DARK_GREY);
    tft.drawFastHLine(0, SCR_H / 2, SCR_W, C_DARK_GREY);
    // Title strip
    tft.fillRect(0, 0, SCR_W, 22, C_GOBLIN_DARK);
    tft.setTextColor(C_GOBLIN_SKIN, C_GOBLIN_DARK);
    tft.setTextSize(2);
    tft.setCursor(140, 3);
    tft.print("SIGNAL GOBLIN");
    menuReady = true;
  }

  // Card positions: 2×2 grid
  int cx[4] = { SCR_W/4, 3*SCR_W/4, SCR_W/4, 3*SCR_W/4 };
  int cy[4] = { SCR_H/4 + 11, SCR_H/4 + 11, 3*SCR_H/4, 3*SCR_H/4 };

  for (int i = 0; i < 4; i++) {
    drawMenuCard(i, cx[i], cy[i], menuEntries[i].colour, hoverIdx == i);
  }
}

void drawMenuGoblinAnim(int frame) {
  // Small animated goblin in the center cross-point
  tft.fillRect(SCR_W/2 - 32, SCR_H/2 - 36, 64, 72, C_BLACK);
  Goblin::drawBoot(tft, SCR_W/2 - 32, SCR_H/2 - 36, frame);
}

int menuHitTest(int16_t tx, int16_t ty) {
  for (int i = 0; i < 4; i++) {
    if (tx >= menuEntries[i].bx && tx < menuEntries[i].bx + menuEntries[i].bw &&
        ty >= menuEntries[i].by && ty < menuEntries[i].by + menuEntries[i].bh) {
      return i;
    }
  }
  return -1;
}

// ──────────────────────────────────────────────────────────────────────────
//  RFID Screen
// ──────────────────────────────────────────────────────────────────────────
void enterRFID() {
  tft.fillScreen(C_BLACK);
  drawHeader("RFID / NFC", C_GREEN);
  drawBackBtn();
  tft.setTextColor(C_LIGHT_GREY, C_BLACK);
  tft.setTextSize(1);
  tft.setCursor(10, 45);
  tft.print("Tap a Mifare/ISO14443A card to the sensor.");
  drawStatusBar("Waiting for card...", C_GREEN, C_DARK_GREY);
}

void animateRFID(int frame) {
  tft.fillRect(0, 80, SCR_W, 200, C_BLACK);
  // Two goblins — one reading, one watching
  Goblin::drawRFID(tft, 60, 90, frame);
  // Scanning arc around PN532
  int r = 30 + (frame % 6) * 8;
  tft.drawCircle(280, 185, r, (frame % 3 == 0) ? C_GREEN : C_DARK_GREEN);
  // PN532 module outline
  tft.fillRoundRect(240, 155, 80, 60, 5, 0x0300);
  tft.drawRoundRect(240, 155, 80, 60, 5, C_GREEN);
  tft.setTextColor(C_GREEN, 0x0300);
  tft.setTextSize(1);
  tft.setCursor(252, 172);
  tft.print("PN532");
  tft.setCursor(248, 185);
  tft.print("I2C: 0x24");
}

void processRFID() {
  uint8_t uid[7];
  uint8_t uidLen = 0;
  if (nfc.readPassiveTargetID(PN532_MIFARE_ISO14443A, uid, &uidLen, 50)) {
    char buf[64] = "UID: ";
    for (uint8_t i = 0; i < uidLen; i++) {
      char hex[4];
      snprintf(hex, sizeof(hex), "%02X ", uid[i]);
      strncat(buf, hex, sizeof(buf) - strlen(buf) - 1);
    }
    drawStatusBar(buf, C_YELLOW, C_DARK_GREY);
    setLED(false, true, false);
    delay(100);
    setLED(false, false, false);
  }
}

// ──────────────────────────────────────────────────────────────────────────
//  CC1101 Screen
// ──────────────────────────────────────────────────────────────────────────
void enterCC1101() {
  tft.fillScreen(C_BLACK);
  drawHeader("CC1101  433MHz", C_ORANGE);
  drawBackBtn();
  tft.setTextColor(C_LIGHT_GREY, C_BLACK);
  tft.setTextSize(1);
  tft.setCursor(10, 45);
  tft.print("Tap lower half to TX a test packet.");
  drawStatusBar("RX mode — listening at 433.92 MHz", C_ORANGE, C_DARK_GREY);
  ELECHOUSE_cc1101.Init();
  ELECHOUSE_cc1101.setMHZ(433.92);
  ELECHOUSE_cc1101.SetRx();
}

void animateCC1101(int frame) {
  tft.fillRect(0, 80, SCR_W, 200, C_BLACK);
  Goblin::drawCC1101(tft, 50, 90, frame);
  // Waterfall-style frequency display
  for (int col = 0; col < 300; col++) {
    uint8_t v = (uint8_t)(128 + 100 * sin((col + frame * 4) * 0.08));
    uint16_t c = tft.color565(v / 4, v / 2, v > 128 ? 255 : v * 2);
    tft.drawFastVLine(150 + col, 250 - v / 6, v / 6, c);
  }
  tft.setTextColor(C_ORANGE, C_BLACK);
  tft.setTextSize(1);
  tft.setCursor(150, 255);
  tft.print("433.92 MHz sub-GHz");
}
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
void loop() {
  tickAnim();
  int16_t tx = 0, ty = 0;
  bool touched = getTouch(tx, ty);

  switch (currentScreen) {

    // ── Menu ──────────────────────────────────────────────────────────────
    case SCR_MENU: {
      int hover = touched ? menuHitTest(tx, ty) : -1;
      // Only redraw on touch to avoid flicker
      static int lastHover = -99;
      if (animFrame % 4 == 0) drawMenuGoblinAnim(animFrame);
      if (hover != lastHover) {
        drawMainMenu(hover);
        drawMenuGoblinAnim(animFrame);
        lastHover = hover;
      }
      if (touched && hover >= 0) {
        delay(120);
        menuReady = false;
        currentScreen = menuEntries[hover].target;
        switch (currentScreen) {
          case SCR_RFID:   enterRFID();   break;
          case SCR_CC1101: enterCC1101(); break;
          case SCR_NRF24:  enterNRF24();  break;
          case SCR_IR:     enterIR();     break;
          default: break;
        }
      }
      break;
    }

    // ── RFID ──────────────────────────────────────────────────────────────
    case SCR_RFID:
      if (animFrame % 2 == 0) animateRFID(animFrame);
      processRFID();
      if (touched && backTouched(tx, ty)) {
        menuReady = false; currentScreen = SCR_MENU;
        drawMainMenu(); drawMenuGoblinAnim(0);
      }
      break;

    // ── CC1101 ────────────────────────────────────────────────────────────
    case SCR_CC1101:
      if (animFrame % 2 == 0) animateCC1101(animFrame);
      processCC1101(tx, ty, touched);
      if (touched && backTouched(tx, ty)) {
        menuReady = false; currentScreen = SCR_MENU;
        drawMainMenu(); drawMenuGoblinAnim(0);
      }
      break;

    // ── nRF24 ─────────────────────────────────────────────────────────────
    case SCR_NRF24:
      if (animFrame % 2 == 0) animateNRF24(animFrame);
      processNRF24(tx, ty, touched);
      if (touched && backTouched(tx, ty)) {
        radio.stopListening();
        menuReady = false; currentScreen = SCR_MENU;
        drawMainMenu(); drawMenuGoblinAnim(0);
      }
      break;

    // ── IR ────────────────────────────────────────────────────────────────
    case SCR_IR:
      if (animFrame % 2 == 0) animateIR(animFrame);
      processIR(tx, ty, touched);
      if (touched && backTouched(tx, ty)) {
        irrecv.disableIRIn();
        menuReady = false; currentScreen = SCR_MENU;
        drawMainMenu(); drawMenuGoblinAnim(0);
      }
      break;

    default: break;
  }

  delay(8);
}

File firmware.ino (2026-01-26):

// ============================================================================
//  Signal Goblin – ESP32-32E Firmware
//
//  This sketch is written for the LCDwiki 3.5‑inch ESP32‑32E display module. It
//  demonstrates how to integrate several external radios and sensors on a
//  single ESP32 development board with a touch GUI.  The firmware includes
//  basic support for an Adafruit PN532 NFC reader (I²C), a CC1101 sub‑GHz
//  transceiver, an nRF24L01+ 2.4 GHz transceiver, and a generic IR receiver
//  / transmitter module.  A simple menu system with touch navigation is
//  implemented and colourful “goblin” icons are drawn on the screen to make
//  each module’s function easily identifiable.  When the device boots up a
//  power‑on animation is shown.  All images are stored in program memory
//  (PROGMEM) to conserve SRAM.
//
//  Pin assignments for the ESP32‑32E module are derived from the official
//  LCDwiki resource table【520313396163434†L276-L334】.  The PN532 operates in
//  I²C mode using pins 25 (SCL) and 32 (SDA).  The nRF24L01+ and CC1101 share
//  the VSPI bus (SCLK on IO18, MISO on IO19 and MOSI on IO23).  Unique chip
//  select and control pins are provided for each transceiver.  An IR receiver
//  is attached to an input‑only pin (IO34) and an IR transmitter uses
//  IO16.  See the schematic comments below for details.
//
//  References
//  ----------
//  • The LCDwiki resource table documents how the ESP32 pins are wired to
//    on‑board peripherals such as the LCD, touch controller, SD card, RGB LED
//    and more【520313396163434†L276-L334】.
//  • The ELECHOUSE_CC1101 library manual lists the CC1101 connections.  It
//    states that VCC, GND, SCLK, SI (MOSI), SO (MISO) and CSN must be wired
//    to the MCU’s SPI pins and that the module provides two status outputs
//    GDO0 and GDO2【956622895956683†L18-L41】.
//  • Using the PN532 in I²C mode requires only two wires (SDA & SCL) and the
//    address is 0x24 when switch 1 is ON and switch 2 is OFF【379350913003354†L440-L447】.  Pull‑up
//    resistors are typically built into the ESP32.
//  • An IR receiver module is connected to the ESP32 by wiring its GND to
//    ground, VCC to 3.3 V and the signal pin to a GPIO (Pin 4 is used in the
//    Makerguides example【672710659831506†L274-L284】).  We reuse the same wiring concept and
//    attach our receiver to IO34 (input only).  The IRremote library handles
//    decoding.
//
//  Created: January 2026 (America/Los_Angeles)
//  Author: ChatGPT (with references cited above)
// ============================================================================

#include <Arduino.h>

// ==== Display and touch libraries ===================================================
#include <TFT_eSPI.h>          // Efficient TFT library (needs configuration)
#include <XPT2046_Touchscreen.h> // Resistive touch controller

// ==== Communications and sensor libraries =========================================
#include <Wire.h>              // I²C bus for PN532
#include <Adafruit_PN532.h>    // NFC / RFID reader
#include <RF24.h>              // nRF24L01+ transceiver
#include <ELECHOUSE_CC1101.h>  // CC1101 sub‑GHz transceiver
#include <IRremote.hpp>        // IR transmitter/receiver

// ==== Image assets stored in PROGMEM ==============================================
// The goblin icons and startup animation are generated ahead of time using an
// offline Python script.  Each image is converted to RGB565 format and stored
// in flash.  See `goblin_images.h` for definitions.
#include "goblin_images.h"

// ==== Pin definitions ==============================================================
// ESP32‑32E LCD pins (hard‑wired on the board).  These values match the
// LCDwiki pin assignment table【520313396163434†L276-L334】.  Only BL_PIN is used here
// because TFT_eSPI takes care of the rest via its configuration.
static const uint8_t BL_PIN      = 27; // Backlight control (high = on)
static const uint8_t RESET_PIN   =  0; // EN pin tied to IO0 (not used)

// Touch controller pins (connected to XPT2046 on the display board).
static const uint8_t TOUCH_CS_PIN  = 33;
static const uint8_t TOUCH_IRQ_PIN = 36;

// I²C pins for PN532 (use the I²C peripheral defined in LCDwiki table).  The
// PN532 address defaults to 0x24 when configured for I²C【379350913003354†L440-L447】.
static const uint8_t I2C_SCL_PIN = 25;
static const uint8_t I2C_SDA_PIN = 32;

// nRF24L01+ connections (VSPI bus).  SCK, MOSI and MISO are provided by
// IO18, IO23 and IO19 respectively; see the LCDwiki table under “SPI
// Peripheral”【520313396163434†L321-L334】.
static const uint8_t NRF_CE_PIN  = 26; // Chip enable; repurposed from DAC output
static const uint8_t NRF_CSN_PIN = 21; // Chip select for external SPI peripheral

// CC1101 connections (VSPI bus).  CSN is shared with the SD card on IO5 – here
// we repurpose IO5 for the CC1101.  GDO0/GDO2 are output only lines from the
// CC1101 and connect to input‑only ESP32 pins (IO35 and IO39)【956622895956683†L18-L41】.
static const uint8_t CC1101_CSN_PIN  = 5;
static const uint8_t CC1101_GDO0_PIN = 35;
static const uint8_t CC1101_GDO2_PIN = 39;

// IR module pins.  A typical IR receiver is wired with VCC, GND and a signal
// pin; the signal is connected here to IO34 (input only)【672710659831506†L274-L284】.  An
// IR LED transmitter uses IO16 as an output.
static const uint8_t IR_RECEIVE_PIN  = 34;
static const uint8_t IR_TRANSMIT_PIN = 16;

// ==== Globals for hardware drivers =================================================

// TFT and touch drivers.  The TFT_eSPI library expects a configuration file
// named `User_Setup_Select.h` to be present in its installation.  For this
// project we override the default pins via macros defined in a custom
// `User_Setup.h`.  If you installed TFT_eSPI normally, copy the following
// definitions into your `User_Setup.h` file before compiling:
//   #define TFT_MISO 12
//   #define TFT_MOSI 13
//   #define TFT_SCLK 14
//   #define TFT_CS   15
//   #define TFT_DC    2
//   #define TFT_RST  -1
//   #define TFT_BL   27
// Alternatively you can place these definitions above the inclusion of
// TFT_eSPI in this file.  See the TFT_eSPI documentation for details.
TFT_eSPI tft = TFT_eSPI();

// XPT2046 touch controller (uses SPI0 on the display board).  The pins are
// provided explicitly.  Note: the SPI bus is shared with the LCD.
XPT2046_Touchscreen touch(TOUCH_CS_PIN, TOUCH_IRQ_PIN);

// PN532 NFC reader (I²C).  Using the Adafruit driver with default I²C
// address (0x24) when the module is configured for I²C mode【379350913003354†L440-L447】.
Adafruit_PN532 nfc = Adafruit_PN532(I2C_SDA_PIN, I2C_SCL_PIN);

// nRF24L01+ transceiver on VSPI bus.  The RF24 library uses the default
// SPI peripheral automatically when instantiated.  Provide CE and CSN pins.
RF24 radio(NRF_CE_PIN, NRF_CSN_PIN);

// IR remote library instances.
IRrecv irrecv(IR_RECEIVE_PIN);
IRsend irsend(IR_TRANSMIT_PIN);
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

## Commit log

2026-01-26 Tft driver install
    // ===== TFT_eSPI local setup (project-only) =====
    // Put this file in the SAME folder as Signal_Goblin.ino
    // Pick ONE driver:
    //#define ST7789_DRIVER // Use if your display is 240x320
    #define ST7796_DRIVER // Use if your display is 320x480
    // Display size:
    #define TFT_WIDTH 320
    #define TFT_HEIGHT 480
    // If you switch to ST7789, use:
    // #define TFT_WIDTH 240
    // #define TFT_HEIGHT 320
    // SPI pins (shared bus)
    #define TFT_MOSI 13
    #define TFT_MISO 12
    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
    [firmware.ino, firmware_stm32.ino]
2026-03-17 Jlcpcb json files and schematics
2026-06-10 Add files via upload
    Some more files for the Goblin to creep
    [Signal_Goblin.DRL, Signal_Goblin.GBL, Signal_Goblin.GKO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]
2026-06-10 Fix formatting for 3.5" TFT Display entry
    [Signal_Goblin_TCB_BOM_v2.csv]
2026-06-10 Beautify BOM: Convert CSV to formatted markdown tables with organized sections
2026-06-10 Improve Signal Goblin BOM v2: fix truncations, add RF sim status, enhance power/thermal notes, add sourcing details
    [Signal_Goblin_TCB_BOM_v2.csv]
